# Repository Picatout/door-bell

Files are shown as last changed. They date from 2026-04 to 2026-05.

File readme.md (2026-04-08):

# sonette de porte réalisée avec un STM8L151K6

Ce projet utilise le convertisseur Numérique/Analogique du MCU __STM8L151K6__  pour jouer un fichier au format __WAV__ enregistré dans une mémoire FLASH Windond __W25Q80DV__.  L'application est entièrement écrite en [smallForth](https://github.com/Picatout/smallForth) et comprend les 4 fichiers suivants:
1.  [exist.f](forth/exist.f)
1.  [w25q_prog.f](forth/w25q_prog.f)
1.  [play_wav.f](forth/play_wav.f)
1.  [door-bell.f](forth/door-bell.f) 

## Schématique du circuit

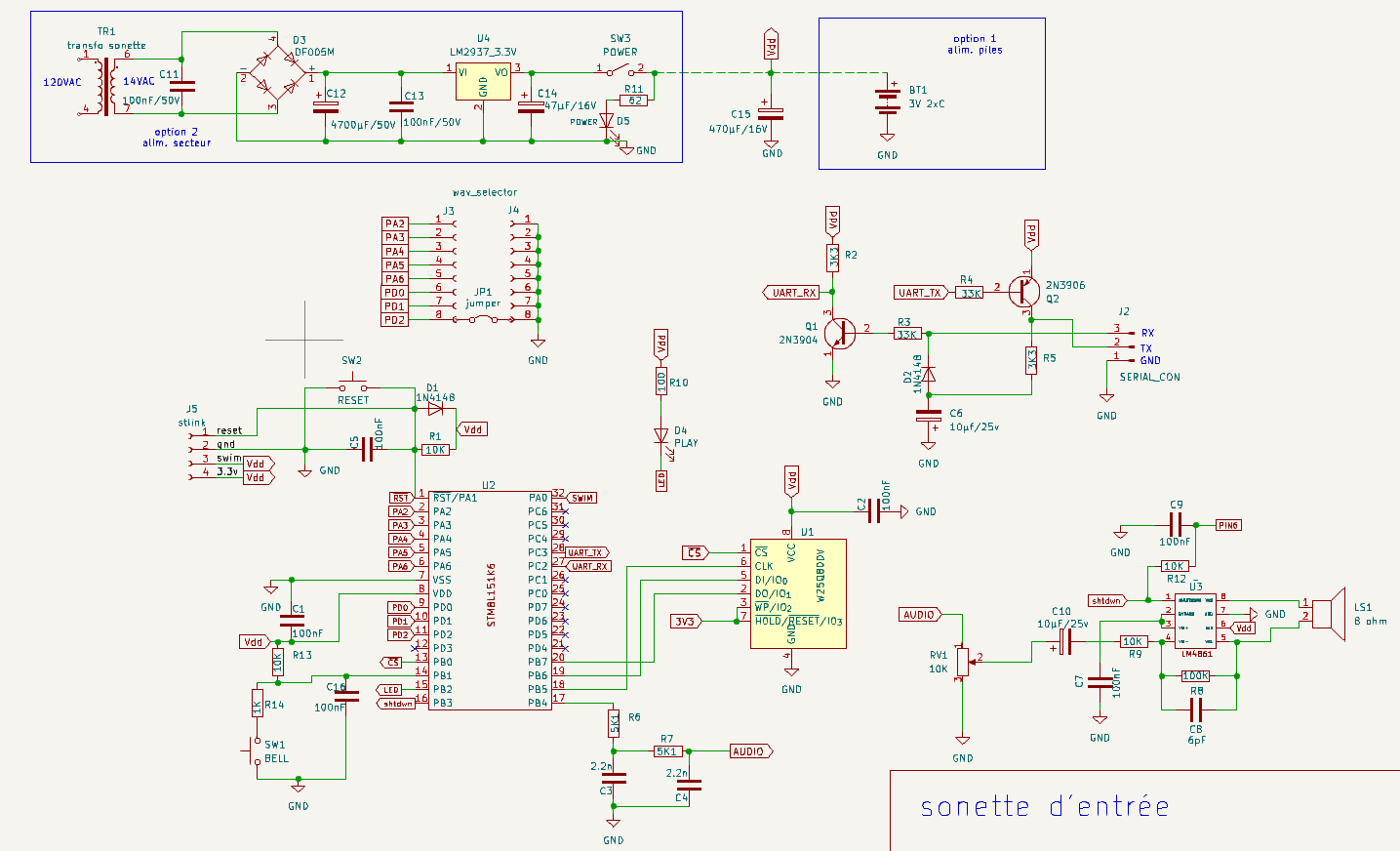
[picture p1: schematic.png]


## Utilisation des périphériques du STM8L151K6

1. Le __DAC__ convertie les échantillons PCM du fichier __WAV__ en signal de sortie analogique.
1. La minuterie __TIMER4__ est programmée pour cadencer le transfert des échantillons PCM au __DAC__ à la fréquence requise de 22050 Hertz.
1. Le canal 3 du __DMA__ transfert les échantillons du tampon RAM vers le __DAC__ et génère une interruption à mi-chemin ainsi qu'à la find du tampon. 
1. Le __SPI__ fait la lecture du fichier __WAV__ qui est sur la __W25Q80DV__ vers le tampon. La moitié du tampon est chargée tandis que le __DMA__ transfert l'autre moitié au __DAC__. Cette technique permet un transfert continu sans délais entre échantillons.

## Montage 

montage

## Programmation du MCU 

1.  Utiliser un programmeur STLINK_V2 pour installer le firmware  [smallForth](build/stm8l151k6/smallForth.bin) avec la commande. 
```
stm8flash -c stlinkv2 -p stm8l151k6 build/stm8l151k6/smallForth.bin
```
1. smallForth communicque avec l'utilisateur via un émulateur de terminal. J'utilise GTKTerm sur Ubuntu 22.04LTS. La configuration du terminal est __115200 BAUD,8 bits,1 stop, pas de parité, pas de contrôle de flux.__ Voir la schématique pour l'agencement du connecteur __serial_con__. 
1. Le reste de la programmation se fait avec le script [prog_sonette.sh](prog_sonette.sh) qui envoie les 4 fichiers forth de l'application à la carte. Cette opération prend quelques minutes. On voit le texte du code source défilé à l'écran et sur le terminal.
```
./prog_sonette.sh
```
3. Ensuite il faut programmer les fichiers __WAV__ dans la mémoire FLASH  __W25Q80DV__.  Il y en a 8 a programmer et ça prend entre 3 et 5 minutes par fichier en utilsant le script [send.sh](send.sh). Encore une fois on voit le texte défilé sur les 2 moniteurs pendant la programmation. Les 8 fichiers sont:
    1. [big-ben.hex](big-ben.hex), joue le Westminster quarter chime.
    1. [code-et.hex](code-et.hex), joue le code ET du film rencontre du 3ième type. 
    1. [gong.hex](gong.hex), joue un son de gong. 
    1. [jeux-interdits.hex](jeux-interdits.hex), joue la musique thème du film les jeux interdits.
    1. [kongas.hex](kongas.hex), joue des tambours Africains.
    1. [koro.hex](koro.hex),  joue le thème Korobeiniki de la version originale de Tétris. 
    1. [ode_joie.hex](ode_joie.hex), Joue l'hymne Européen.
    1. [romans.hex](romans.hex), joue des trompettes romaines.
 
 Tous ces fichiers sont échantillonnés à __8 bits non signés PCM à la fréquence de 22050 hertz__ et convertie en fichier texte par le script [bin2txt.sh](bin2txt.sh). J'ai utilisé le logiciel Audacity pour extraire des séquence de 4 ou 5 secondes et pour exporter sous le format requis par ce projet. Une ligne supplémentaire est ajoutée manuellement au début de chaque fichier. Il s'agit de la commande forth:
 ```
 PROG_BUFF  ud1 ud2 RX_FILE 
 ```
 * **ud1** est un entier double (32 bits) représentant l'adresse W25Q80DV où doit-être enregistré ce fichier. La partie faible précède la partie lourde.
 * **ud2** est un entier double représentant la taille du fichier WAV en octets. Ce nombre doit aussi être entré en format *little indian* à la place des 4 zéros de la deuxième ligne. Tous les nombres sont représentés en hexadécimal. Voici en exemple les 2 premières ligne du fichier [gong.hex](gong.hex)
 Les 12 premiers octets de la deuxième ligne représente le nom du fichier en ASCII. Si le nom a moins de 12 caractères des espaces , caractère ASCII __20__, comble le champ. Ainsi représenté **GONG** est **47 4F 4E 47**  suivit de 8 espaces pour combler le champ.
 ```
 PROG_BUFF $8000 8 $EB50 2 RX_FILE
 47 4F 4E 47 20 20 20 20 20 20 20 20 50 EB 02 00
 ```
Le fichier sera donc programmé à l'adresse __0x88000__ sur la __W25Q80DV__ et la taille du fichier est de __0x2EB50 octets.__ Notez les 4 derniers octets de la 2ième ligne __50 EB 02 00__  c'est encore la taille du fichier saisie au format *little indian*. 

Donc lorsque ces fichiers __HEX__ sont formattés correctement on utilise le script [prog_wav.sh](prog_wav.sh) comme suit:
```
./prog_wav.sh nom_du_fichier
```

La dernière étape est de configurer l'autorun pour que l'application démarre automatique lors de la mise sous tension du circuit. dans la console forth il suffit de faire:
```
AUTORUN DOOR-BELL
```
Redémarrez le MCU en pesant sur le bouton __RESET__. Au démarrage l'application laisse à l'utilisateur 5 secondes pour annuler l'application. Presser n'importe quel touche au clavier annule l'exécution de __DOOR-BELL__ avec retour sur la ligne de commande du forth.

## ATTENTION

**Dans tous les scripts qui utilise l'utilitaire [SendFile](tools/SendFile) le nom du port sériel que vous utilisez doit remplacer celui indiqué par défaut dans le fichier script.**

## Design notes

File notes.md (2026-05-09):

# Notes de projet

### 2026-05-09 

* Modification du circuit pour ajouter la résistance de 1Ko en série avec le fil du bouton de la sonnette. Le fil agissant comme une antenne captait les impulsion RF ce qui avait pour effet de déclencher la sonnerie.
 
### 2026-04-08 

* Modifié schématique du circuit pour ajouter la résistance **R12**  comme pullup sur la broche 1 du **LM4861**
* Installé la version 1.1R7 de smnallForth 
* Modifié [door-bell.f](forth$door-bell.f) pour mettre à profit le mot **DOES&gt;** qui est inclus dans smallForth 1.1R7.

### 2026-04-05 

* Modification à [door-bell.f](forth$door-bell.f) pour réduire la consommation électrique lorsqu'en attente. Avec cette modificaton le circuit consomme 80µA lorsqu'en attente. Alimenté avec 2 piles C la duré de vie des piles devraît-être de 5 ans en théorie. Calcul basé sur une capacité 3800mAH ce qui est en déça de la capacité une pile C de bonne qualité.
* Modifié la schématique pour ajouter un concensateur de 470µF/16V à l'alimentation.

### 2026-04-04

* Montage du prototype complété.
* programme [door-bell.f](forth$door-bell.f) complété.

### 2026-04-03

* Schématique complétée dans KiCAD 
* Assemblage prototype presque complété.
* Programmé mémoire FLASH W25Q80 avec les mélodies.

### 2026-03-17 

* Création du circuit de la sonette dans KiCAD.

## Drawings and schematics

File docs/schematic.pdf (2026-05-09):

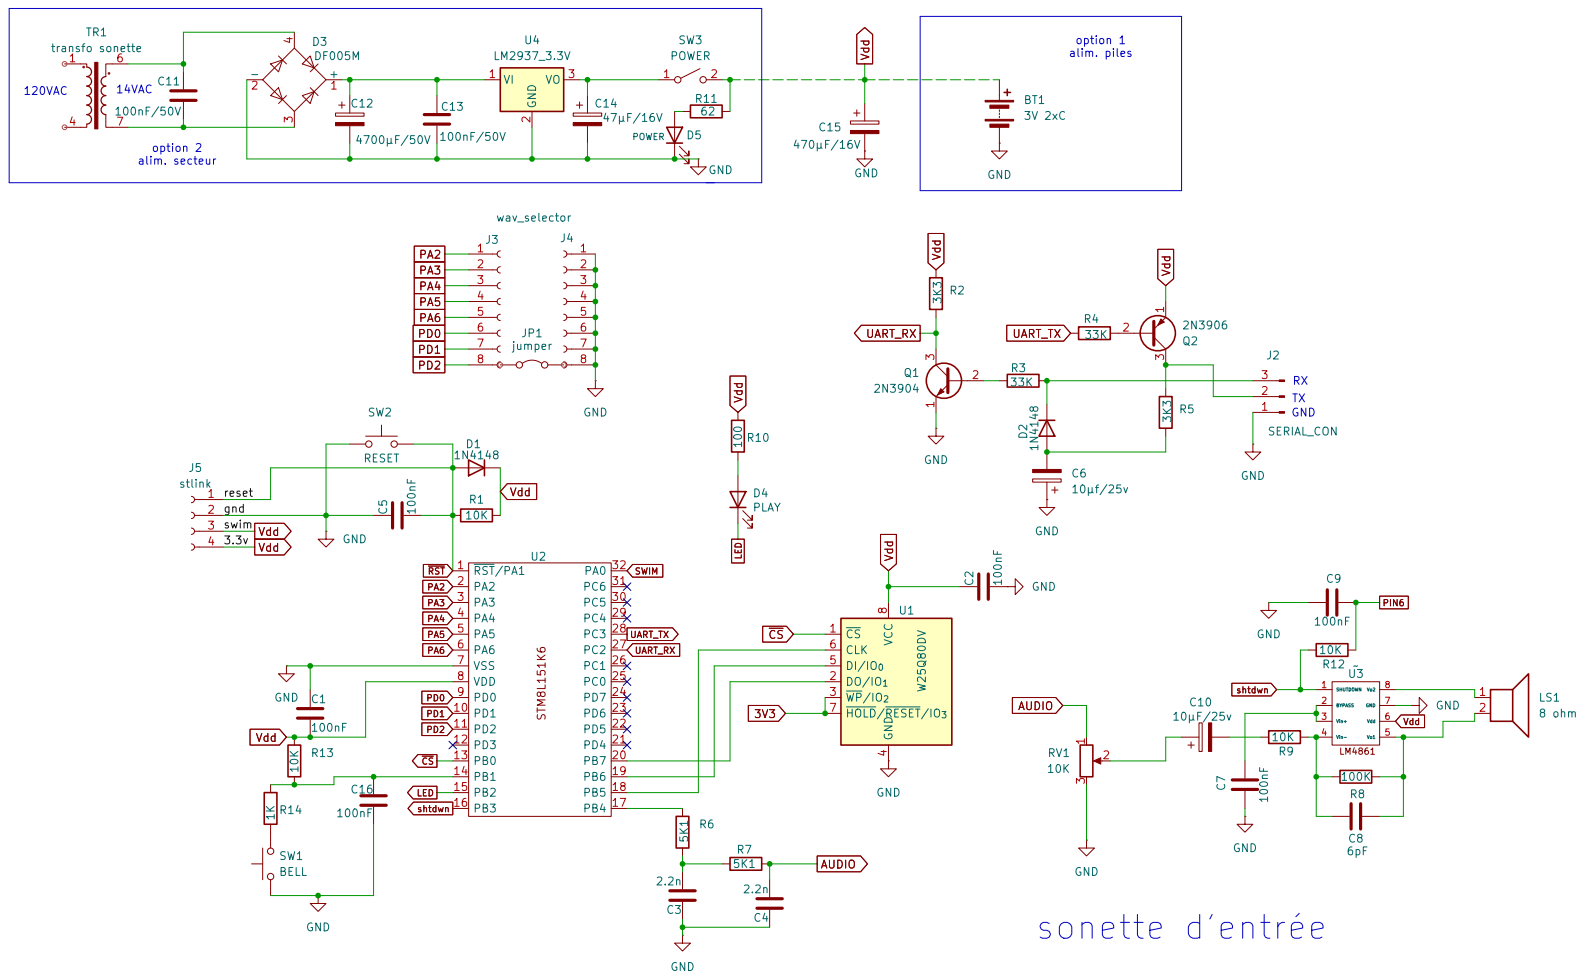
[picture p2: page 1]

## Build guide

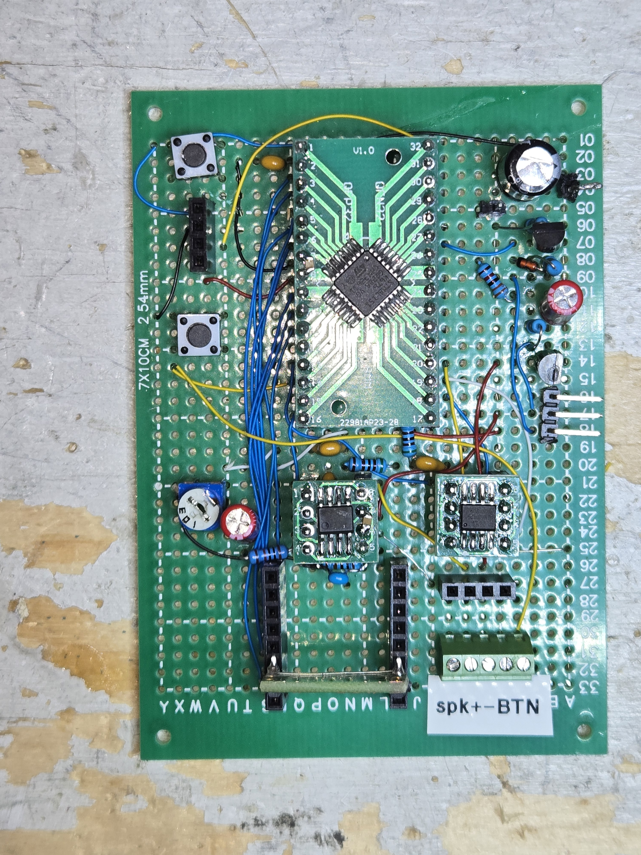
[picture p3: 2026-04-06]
docs/montage-gros-plan.jpg

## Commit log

2026-04-05 premier commit du projet sonette
    [sonette.kicad_pcb, sonette.kicad_sch]
2026-04-05 Modification de door-bell.f pour réduire la consommation lorsqu'en attente.
2026-04-05 Ajout de docs et prog_sonette.sh
2026-04-06 écriture de la documentation dans readme.md
    [sonette.kicad_sch]
2026-04-07 Ajouté une LED au circuit qui s'amulle pendant que le WAV est joué. Modifié forth/door-bell.f pour ajouter le contrôle de la LED
    [sonette.kicad_sch]
2026-04-08 mise à jour smallForth à la version 1.1R7
2026-04-08 Ajout d'un power switch au circuit de l'alimentation secteur
    [sonette.kicad_sch]
2026-04-08 Ajout d'un condensateur électrolytique de 47µF à la sortie du régulateur de tension de l'alimentation secteur.
    [sonette.kicad_sch]
2026-04-08 Ajout d'une note à la fin du fichier readme.md
2026-04-08 Modification à au circuit en ajoutant R12 Modification de door-bell.f pour utilisé le mot DOES>
    [sonette.kicad_sch]
2026-04-13 Modification du circuit pour ajouter un circuit anti-interférance au bouton de la sonette. Ajout de R13 et C16.
    [sonette.kicad_sch]
2026-05-09 Modification du circuit pour ajouter la résistance de 1Ko en série avec le fil du bouton de la sonnette. Le fil agissant comme une antenne captait les impulsion RF ce qui avait pour effet de déclench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
    [sonette.kicad_sch]
